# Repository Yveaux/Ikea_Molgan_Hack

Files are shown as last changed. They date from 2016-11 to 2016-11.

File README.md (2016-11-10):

# Ikea Molgan Hack
This project adds wireless functionality and an Arduino Pro-Mini compatible microntroller to an Ikea Molgan LED light with motion sensor.

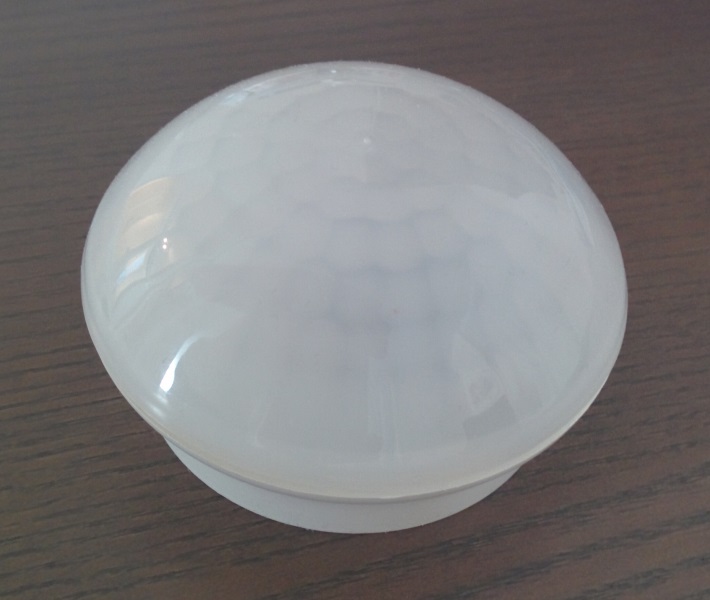
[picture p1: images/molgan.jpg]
Ikea Molgan LED light


Original features
========
* Powered from 3 AAA batteries
* Motion PIR sensor, which switches on the LED light for some time when detecting motion.
* Nice, compact enclosure
* Mounting plate
* Cheap, approx. E 4,99

Hacked features
========
* Atmel ATmega328P microntroller, compatible with Arduino Pro-Mini
* nRF24L01+ 2.4GHz radio module (not WiFi!)
* Optional ATSHA204 CryptoAthentication chip
* Default sketch implements a [MySensors][1] enabled motion sensor
* Serial connector for programming sketches
* ISP for programming the ATmega directly
* LED light function can be removed, either partially or complete, to save battery power
* Quite cheap, around E 10,- including Molgan.

The project consists of a custom PCB, which is mounted on top of the original Molgan PCB.
I had the custom PCB produced in white, to prevent it from being visible trhough the semi-transparent cover of the Molgan.

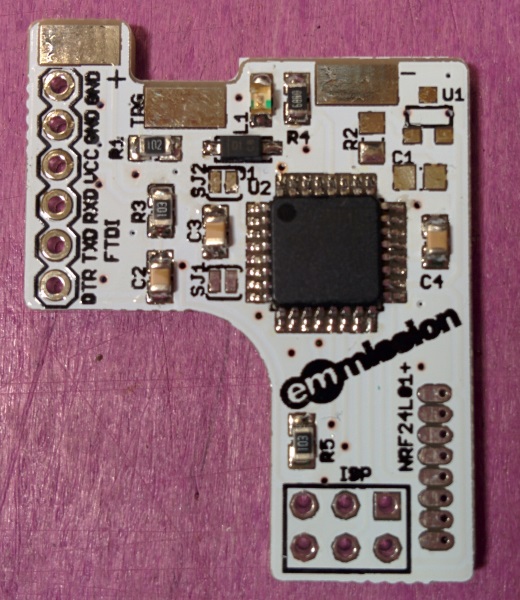
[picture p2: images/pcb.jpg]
Custom addon PCB


What do you need
========
* Ikea Molgan
* Components, as described in the [BOM][2] (LibreOffice Calc format)
* An In-circuit-programmer to flash the ATmega328, or a pre-flashed ATmega328

Add-on PCB construction
========
To keep the PCB small, it is built with SMD components and thus requires quite some soldering skills to put it all together!
Start by mounting the ATmega328, followed by the other SMD components.
The headers are the only through-hole components used, but the bottom of the resulting add-on PCB should be as flat as possible.
I used a wire clipper to clip the ends off the headers before mounting them, as shown in the following picture (bottom image is after clipping).

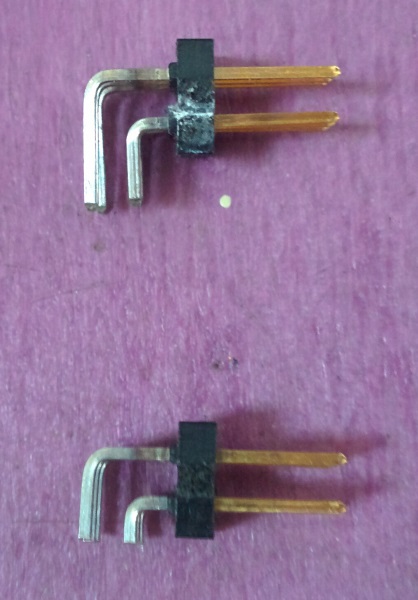
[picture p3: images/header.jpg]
Clipping the headers


Try to insert them without extending below the bottom of the PCB.
Next picture from the side shows how flat it can be.

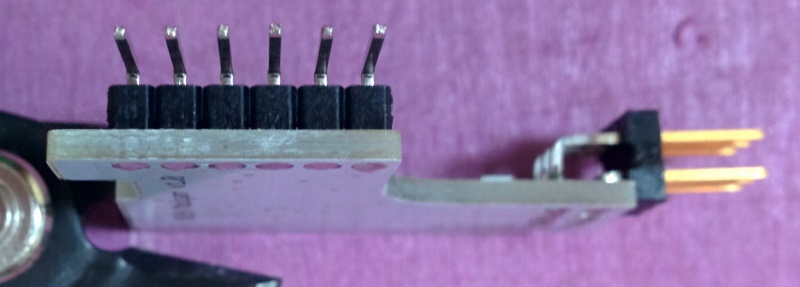
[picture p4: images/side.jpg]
Clipped headers soldered on PCB


Finish by soldering the nRF24L01+ SMD module.

Preparing the Molgan
========
Remove the top cover by carefully prying something flat between the bottom and top cover.
Work your way around carefully, without damaging the enclosure. The Molgan's I opened were all glued together with some double sticky tape which makes them harder to open.
With the top cover removed the PCB reveals itself.

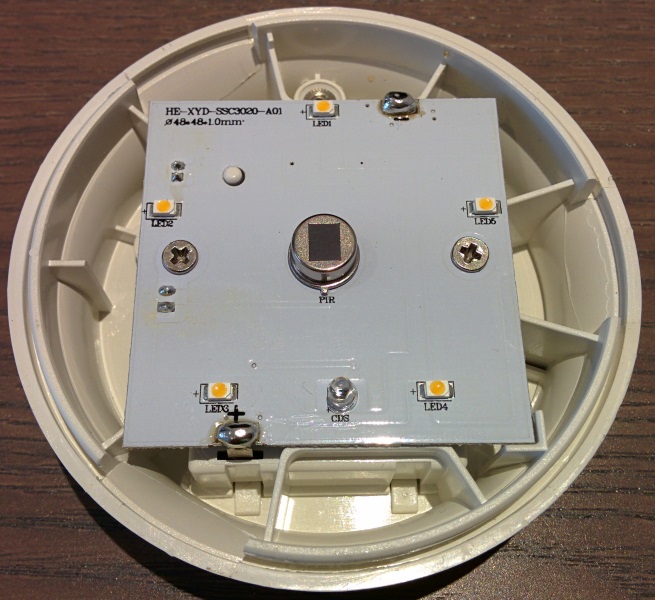
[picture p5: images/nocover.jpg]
Mogan with transparent cover removed


Remove the two screws and the blobs of solder als the + and - connection, which connect the PCB to the battery compartiment.
Flip over the PCB.

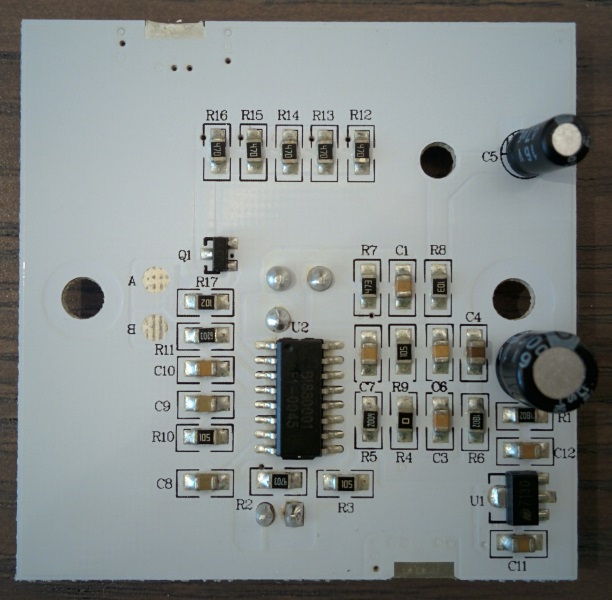
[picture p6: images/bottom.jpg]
Bottom of the Molgan PCB


Now decide if you want to keep the (partial) LED function of the Molgan, or if you turn it into a wireless motion sensor only:
* Resistors R12..R16 are used to power the LEDs at the fron of the PCB. Removing a LED's resitor will effectively disable it.
* Removing resistor R17 disables all LEDs at once.

Solder a small wire to the right pad of R17, which will signal the add-on PCB that motion has been detected.
Make it about as long as on the next picture.

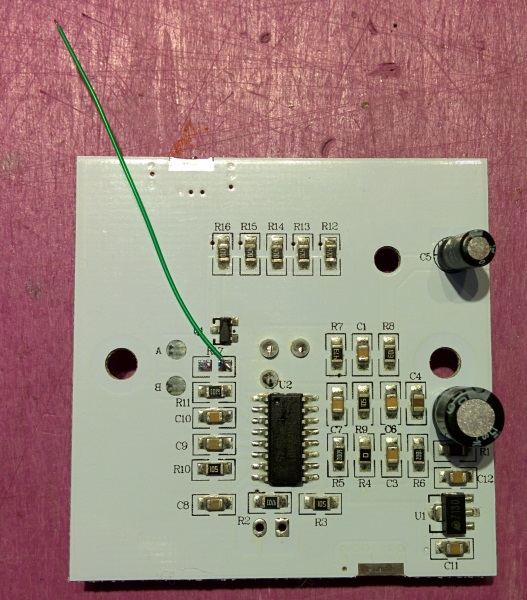
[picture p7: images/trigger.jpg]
Adding the trigger connection


Remove the light sensor on the front (marked 'cds') or the sensor will only detect motion in the dark.
I also replaced R11 by a 120 ohms resistor, to decrease the retrigger time of the PIR to less than a second.

Now drill a small hole next to the battery spring, close to the mounting screw and solder a small wire to the spring base. Use a knife to scratch the surface of the metal a bit or the solder won't stick to it.

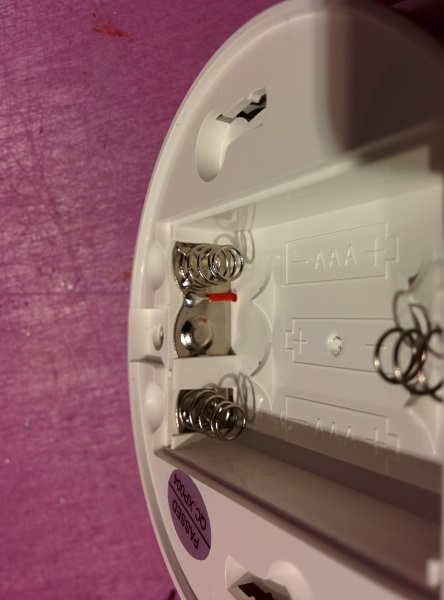
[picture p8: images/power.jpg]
Custom addon pcb power connection


Putting it all together
========
Place the Molgan PCB back into the bottom enclosure and fasten only the left screw.
Align the add-on PCB on top of the Molgan PCB, as shown in the picture.

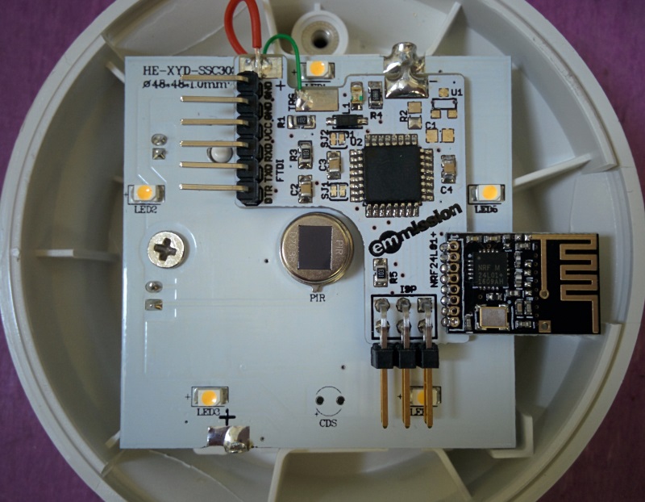
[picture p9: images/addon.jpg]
Custom addon pcb on Molgan


Solder the new power connection from the battery compartment to the + connection of the add-on PCB.
Connect the - on the add-on PCB to the - on the Molgan PCB (I used a small piece of solder wick).
Restore both connections to the batteries.

Flashing the Arduino bootloader
========
This step is required when you acquired a bare ATmega, without Arduino bootlader.
I won't go into details how to do this, as the internet is full of guides, e.g. using an [Arduino][3].

Connect the ISP to the add-on PCB, put some batteries in the Molgan and flash the default Pro-Mini bootloader (called 'ATmegaBOOT_168_atmega328_pro_8MHz.hex') which is part of the Arduino IDE, or can be found [here][4].

Set the fuses to
* EXTENDED: 0xFE
* HIGH: 0xDA
* LOW: 0xE2

Downloading the MySensors motion detector sketch
========
Remove the batteries and connect a standard FTDI serial cable (the ones used to program an Arduino Pro-Mini) to the FTDI connector of the add-on PCB.
Replace the batteries and plug the FTDI cable in your PC.

Start the Arduino IDE and load the [sketch][5].
Change target board to 'Arduino Pro or Pro Mini' and set processor to 'ATmeag328 (3.3V, 8MHz)'.

The sketch will sleep until woken by a motion trigger from the Molgan, or wake up once every 24 hours to check battery level.
It will send a V_TRIPPED message to the gateway and measures the battery level.
For this it uses my [Vcc library][6], whcih should be installed in the IDE.
After a short blind time (set to 30 sec default) the motion sensor is sensitive to triggers again.
This blind time prevents the motion sensor from spamming the gateway with tripped-messages. This time can also be set in hardware (by resistor R11), but software allows for easier tweaking.

The onboard LED is used as a Tx indication by the MySensors library.

Tune the sketch to your liking and upload the sketch.

[1]: https://www.mysensors.org
[2]: https://raw.githubusercontent.com/Yveaux/Ikea_Molgan_Hack/master/pcb/Ikea_Molgan_bom.ods
[3]: https://www.arduino.cc/en/Tutorial/ArduinoISP
[4]: https://github.com/arduino/Arduino/blob/master/hardware/arduino/avr/bootloaders/atmega/ATmegaBOOT_168_atmega328_pro_8MHz.hex
[5]: https://raw.githubusercontent.com/Yveaux/Ikea_Molgan_Hack/master/src/MotionSensor.ino
[6]: https://github.com/Yveaux/Arduino_Vcc

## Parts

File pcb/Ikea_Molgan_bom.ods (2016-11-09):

Qty | Value | Device | Package | Parts | Description | Source | Price (Ex. VAT) | Total (Ex. VAT)
1 |  | IC_ATSHA204A_CRYPT | SOT23-3 | U1 | Optional |  |  | € 0,00
1 |  | LEDCHIPLED_0805 | CHIPLED_0805 | L1 | Yellow, SMD, 2mm x 1.25mm (0805), 20 mA, 2 V, 590 nm | Farnell: 8529914 | € 0,22 | € 0,22
1 |  | M06SIP | 1X06 | FTDI | Header 6x1 (FTDI) | AliExpress | € 0,01 | € 0,01
1 | 1.8V | DIODESOD-123 | SOD-123 | D1 | Zener 1.8V, 500mW, 5% | Farnell: 1858631 | € 0,28 | € 0,28
4 | 100nF | C-EUC0805 | C0805 | C1, C2, C3, C4 | C1 Optional, 10%, X7R, 50V | Farnell: 2496944 | € 0,01 | € 0,06
3 | 10k | R-EU_R0805 | R0805 | R2, R3, R5 | R2 Optional, 100mW, 1%, 150V | Farnell: 9332391 | € 0,00 | € 0,01
1 | 1k | R-EU_R0805 | R0805 | R1 | 100mW, 1%, 150V | Farnell: 9332383 | € 0,00 | € 0,00
1 | 56 | R-EU_R0805 | R0805 | R4 | 125mW, 1%, 150V | Farnell: 2447689 | € 0,01 | € 0,01
1 | AVR-ISP-6 | AVR-ISP-6 | AVR-ISP-6 | ISP | Header 3x2 (ISP) | AliExpress | € 0,01 | € 0,01
1 | MEGA328P-AU | MEGA48/88/168-AU | TQFP32-08 | U2 |  | Farnell: 1715486 | € 2,73 | € 2,73
1 | WIRELESS-NRF24L01SMD2 | WIRELESS-NRF24L01SMD2 | WIRELESS-NRF24L01-SMD-2 | NRF24L01+ | 2.4 GHz Wireless Module based on NRF24L01 chip | AliExpress | € 1,00 | € 1,00
1 | PCB |  |  |  |  | DirtyPcbs.com | € 1,12 | € 1,12
 |  |  |  |  |  |  | Total | € 5,45

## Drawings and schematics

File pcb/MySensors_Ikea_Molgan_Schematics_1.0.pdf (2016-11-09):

# GND VCC

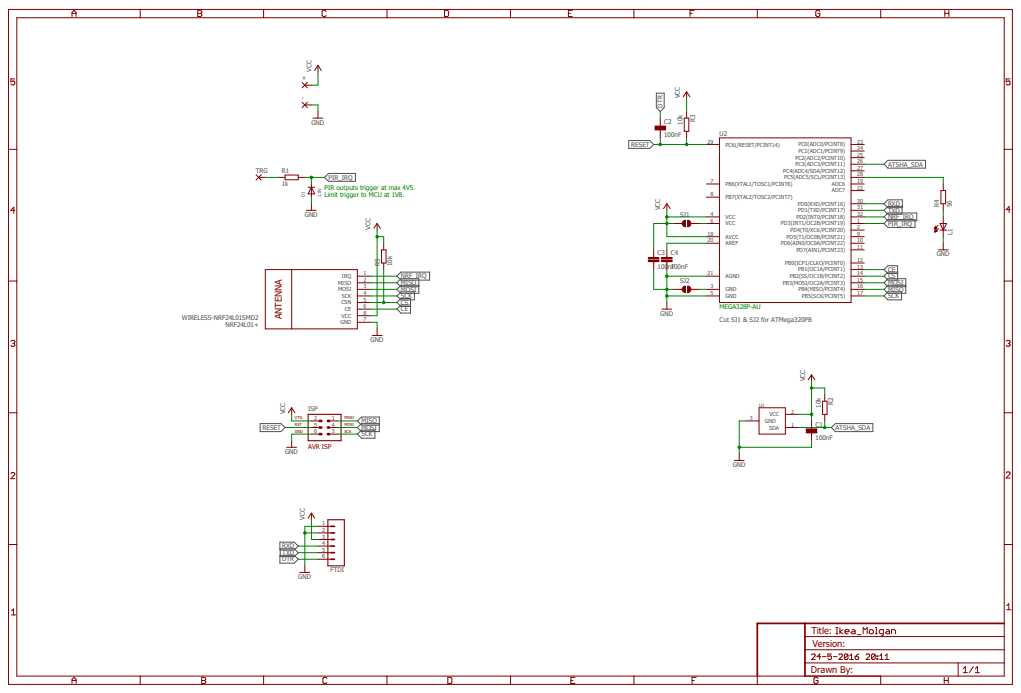
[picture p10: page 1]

PIR_IRQ
PIR outputs trigger at max 4V5.
Limit trigger to MCU at 1V8.

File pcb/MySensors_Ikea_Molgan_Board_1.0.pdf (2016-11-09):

28.00 35.00

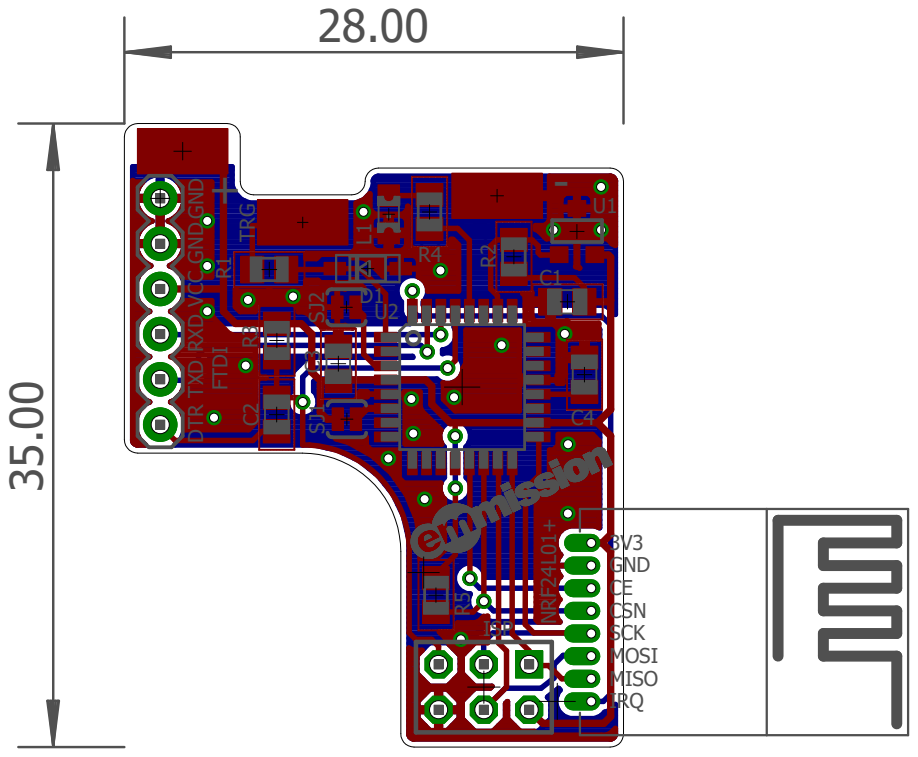
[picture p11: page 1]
U1 NRF24L01+ +; - TRG; ISP FTDI; 3V3 GND CE CSN SCK MOSI MISO IRQ

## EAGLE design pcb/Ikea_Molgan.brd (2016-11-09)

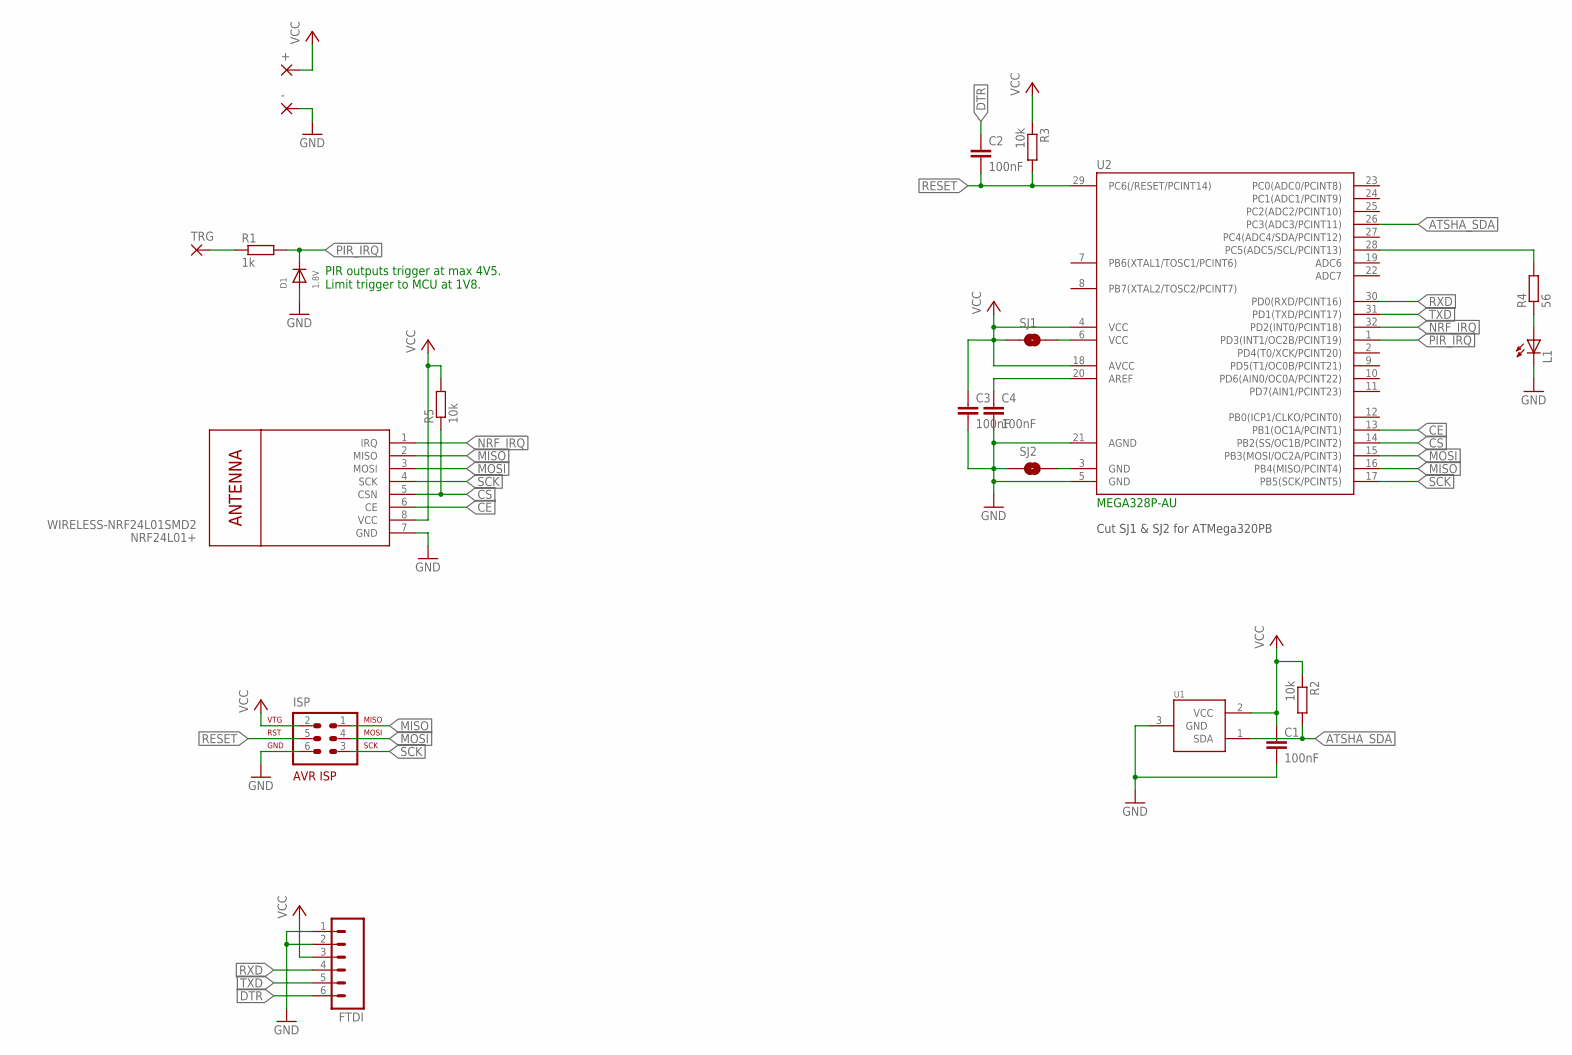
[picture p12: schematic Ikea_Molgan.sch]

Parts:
+: WIREPADSMD2,54-5,08; SMD2,54-5,08
-: WIREPADSMD2,54-5,08; SMD2,54-5,08
C1, C2, C3, C4: 100nF; C0805
D1: 1.8V; SOD-123
FTDI: M06SIP; 1X06
ISP: AVR-ISP-6
L1: LEDCHIPLED_0805; CHIPLED_0805
NRF24L01+: WIRELESS-NRF24L01SMD2; WIRELESS-NRF24L01-SMD-2
R1: 1k; R0805
R2, R3, R5: 10k; R0805
R4: 56; R0805
SJ1, SJ2: SOLDERJUMPERTRACE; SJ_2S-TRACE
TRG: WIREPADSMD2,54-5,08; SMD2,54-5,08
U1: IC_ATSHA204A_CRYPT; SOT23-3
U2: MEGA328P-AU; TQFP32-08

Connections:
ATSHA_SDA: R2.2, U1.1 (SDA), U2.26 (PC3(ADC3/PCINT11))
CE: NRF24L01+.6 (CE), U2.13 (PB1(OC1A/PCINT1))
CS: NRF24L01+.5 (CSN), R5.1, U2.14 (PB2(SS/OC1B/PCINT2))
DTR: C2.1, FTDI.6
GND: -.1, C1.2, C3.2, C4.2, D1.A, FTDI.1, FTDI.2, ISP.6, L1.C, NRF24L01+.7 (GND), SJ2.1, U1.3 (GND), U2.5 (GND), U2.21 (AGND)
MISO: ISP.1, NRF24L01+.2 (MISO), U2.16 (PB4(MISO/PCINT4))
MOSI: ISP.4, NRF24L01+.3 (MOSI), U2.15 (PB3(MOSI/OC2A/PCINT3))
unnamed: R1.1, TRG.1
unnamed: L1.A, R4.1
unnamed: R4.2, U2.28 (PC5(ADC5/SCL/PCINT13))
unnamed: SJ1.2, U2.6 (VCC)
unnamed: SJ2.2, U2.3 (GND)
unnamed: C4.1, U2.20 (AREF)
NRF_IRQ: NRF24L01+.1 (IRQ), U2.32 (PD2(INT0/PCINT18))
PIR_IRQ: D1.C, R1.2, U2.1 (PD3(INT1/OC2B/PCINT19))
RESET: C2.2, ISP.5, R3.2, U2.29 (PC6(/RESET/PCINT14))
RXD: FTDI.4, U2.30 (PD0(RXD/PCINT16))
SCK: ISP.3, NRF24L01+.4 (SCK), U2.17 (PB5(SCK/PCINT5))
TXD: FTDI.5, U2.31 (PD1(TXD/PCINT17))
VCC: +.1, C1.1, C3.1, FTDI.3, ISP.2, NRF24L01+.8 (VCC), R2.1, R3.1, R5.2, SJ1.1, U1.2 (VCC), U2.4 (VCC), U2.18 (AVCC)

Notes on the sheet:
PIR outputs trigger at max 4V5. Limit trigger to MCU at 1V8.
Cut SJ1 & SJ2 for ATMega320PB

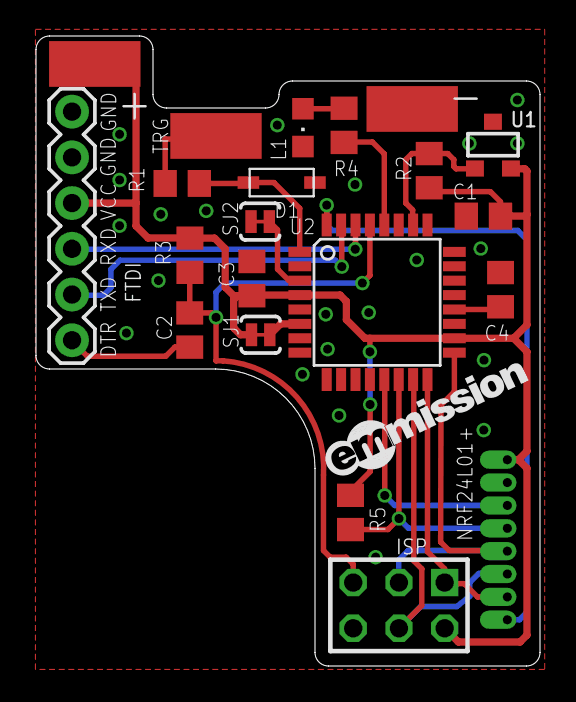
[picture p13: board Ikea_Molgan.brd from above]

Board: 2 copper layers, 28.0 x 35.0 mm, 22 parts (0 on the bottom side), 20 nets.

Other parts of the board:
U$1: EMMISSION_LOGO_12MM_NOTAG

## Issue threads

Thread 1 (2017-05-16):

Vcc

35nine, 2017-05-16:
Hi, a quick question, in the battery wire connection added, it appears you connect to the middle of one spring end plates plate?  Is this correct, you are using only x2 series AAA cells to power the add in board?  Thank you!

Yveaux, 2017-05-17:
Yes, addon board runs from 2xAAA while the Molgan keep running on 3xAAA.

Closed 2017-05-17.

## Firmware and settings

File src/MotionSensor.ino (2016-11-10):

/*
    MotionSensor - A MySensors Motion Sensor sketch for use with hacked Ikea Molgan.

    Created by Ivo Pullens, Emmission, 2016

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
    You should have received a copy of the GNU General Public License
    along with this program.  If not, see <http://www.gnu.org/licenses/>.
*/

#define MY_RADIO_NRF24
#define MY_BAUD_RATE                (57600)

#define MY_WITH_LEDS_BLINKING_INVERSE
#define MY_DEFAULT_TX_LED_PIN       (A5)

#include <MySensors.h>
#include <Vcc.h>

#define PIR_PIN       	            (3)

#define CHILD_ID_PIR                (0)

const float VccMin        = 1.8;             // Minimum expected Vcc level, in Volts: Brownout at 1.8V    -> 0%
const float VccMax        = 2.0 * 1.6;       // Maximum expected Vcc level, in Volts: 2xAAA fresh Alkaline -> 100%
const float VccCorrection = 1.0;             // Measured Vcc by multimeter divided by reported Vcc
static Vcc vcc(VccCorrection);

#define SENSOR_SLEEP_TIME_MS (24UL*60UL*60UL*1000UL)  // Maximum time between sensor wakeups, e.g. to check battery level.
#define PIR_BLIND_TIME_MS    (30UL*1000UL)            // Time PIR will not report new triggers after being triggered

void presentation()
{
  sendSketchInfo("Molgan", "1.0");
  present(CHILD_ID_PIR, S_MOTION);
}

void setup()
{
  pinMode(PIR_PIN, INPUT);
}

void loop()
{
  // Sleep until woken by interrupt or timer.
  bool pirTripped = sleep(digitalPinToInterrupt(PIR_PIN), CHANGE, SENSOR_SLEEP_TIME_MS) >= 0;

  // Only send tripped state. Tripped goes low again after a configurable time on the PIR sensor,
  // and it doesn't make sense to send this state to the gateway. Better save some battery juice.
  // If you still want to send the low level, then remove the if-statement.
  if (pirTripped)
  {
    send( MyMessage(CHILD_ID_PIR, V_TRIPPED).set(uint8_t(pirTripped)) );
  }

  // Try to determine battery level after sending sensor data, so battery will just have experienced some load.
  uint8_t batteryPcnt = static_cast<uint8_t>(0.5 + vcc.Read_Perc(VccMin, VccMax));

  // Battery readout should only go down. So report only when new value is smaller than previous one.
  static uint8_t oldBatteryPcnt = 200;
  if ( batteryPcnt < oldBatteryPcnt )
  {
    sendBatteryLevel(batteryPcnt);
    oldBatteryPcnt = batteryPcnt;
  }

  // Sleep for a short while, ignoring any new triggers.
  if (pirTripped)
  {
    sleep(PIR_BLIND_TIME_MS);
  }
}

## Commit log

2016-11-09 Add PCB
    [Ikea_Molgan.brd, Ikea_Molgan.sch, Ikea_Molgan_bom.ods]
2016-11-09 Add gerbers
    [Ikea_Molgan.GBL, Ikea_Molgan.GBO, Ikea_Molgan.GBS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]
2016-11-10 Added Arduino sketch

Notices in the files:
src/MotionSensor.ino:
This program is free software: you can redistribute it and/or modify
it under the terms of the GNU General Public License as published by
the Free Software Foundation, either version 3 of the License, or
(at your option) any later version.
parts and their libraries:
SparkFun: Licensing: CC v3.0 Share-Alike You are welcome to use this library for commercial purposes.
